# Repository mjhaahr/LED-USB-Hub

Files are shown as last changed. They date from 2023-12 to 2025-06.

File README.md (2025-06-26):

# 3-Port USB Hub with Integrated Microcontroller and RGB USB-A Ports

<!-- ![Assembled USB Hub](images/working-usb-hub.png) -->

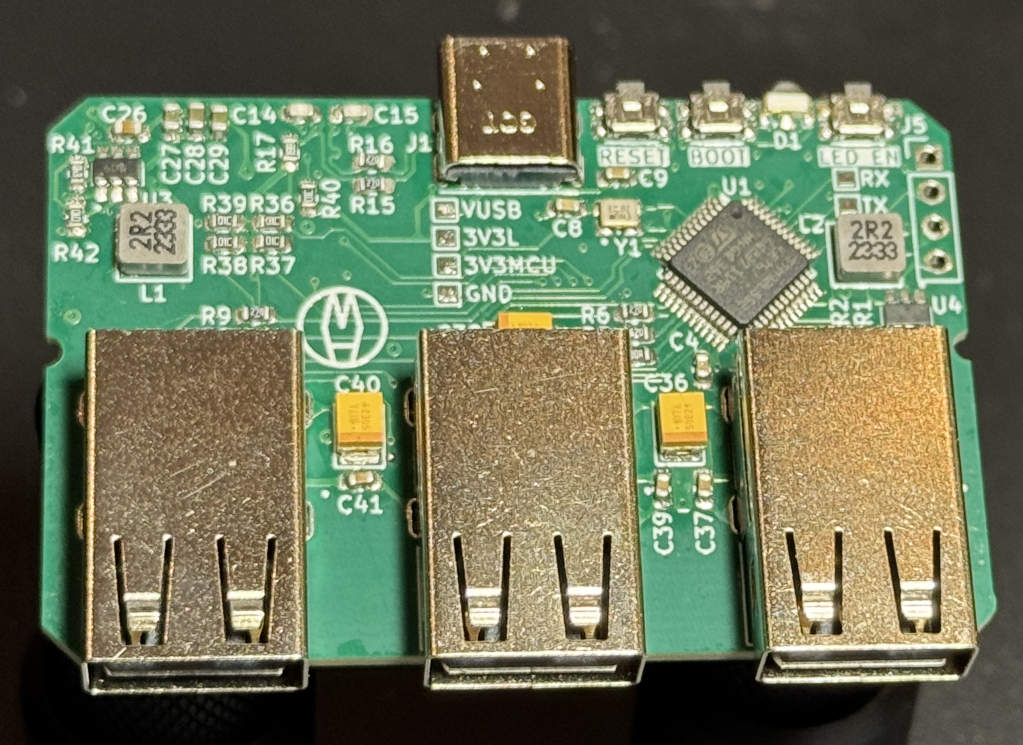
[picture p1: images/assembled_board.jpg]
Assembled PCB


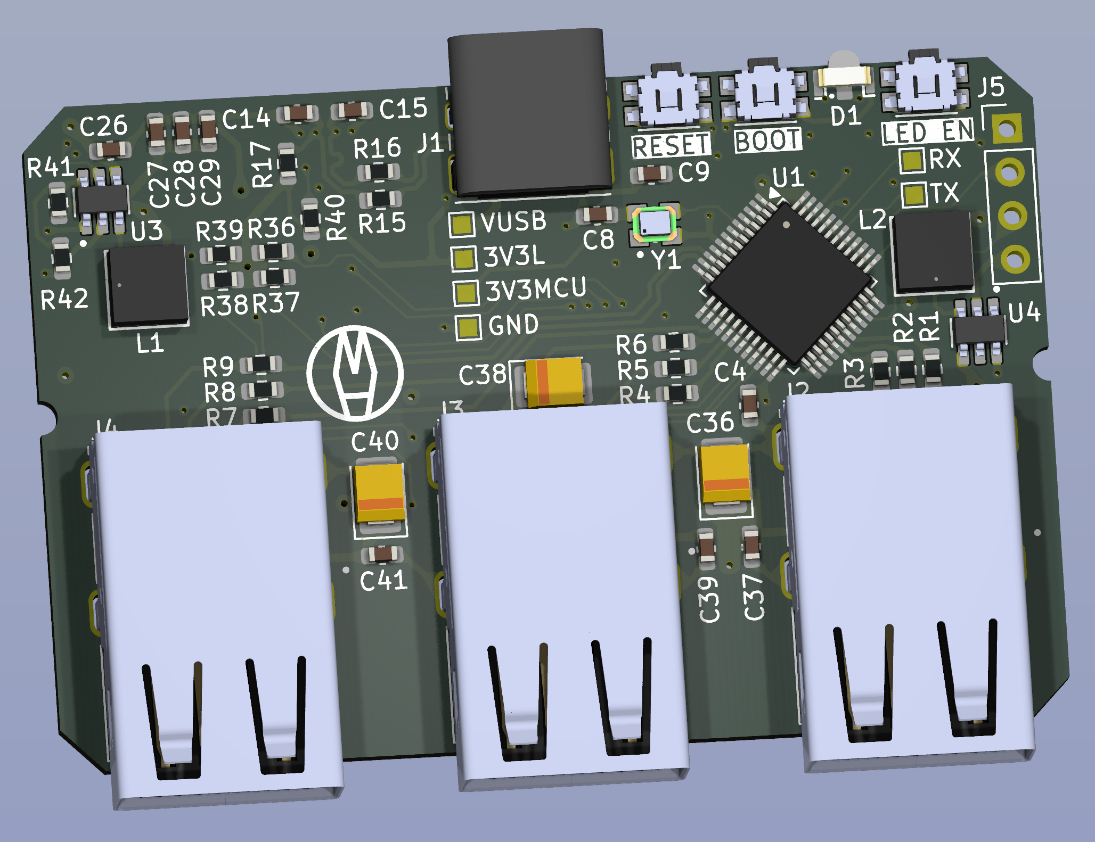
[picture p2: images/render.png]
Full Board Design Render

 
## Features
- USB C Port for Upstream
- 3 USB 2.0 Downstream Ports
    - USB A, Full Speed
    - Using RGB LED USB Ports (the reason behind this whole project)
- STM32L552 to Control the LEDs
    - Intended to be flashed using DFU, but SWD with Reset is available
- USB Hub Controller:
    - Using a TI 4 Port USB Controller
- Status LEDs for Power and USB Connection

## PCBWay
Version 3 of the RGB LED USB Hub was kindly supported by PCBWay, who graciously provided the PCBs for this project.

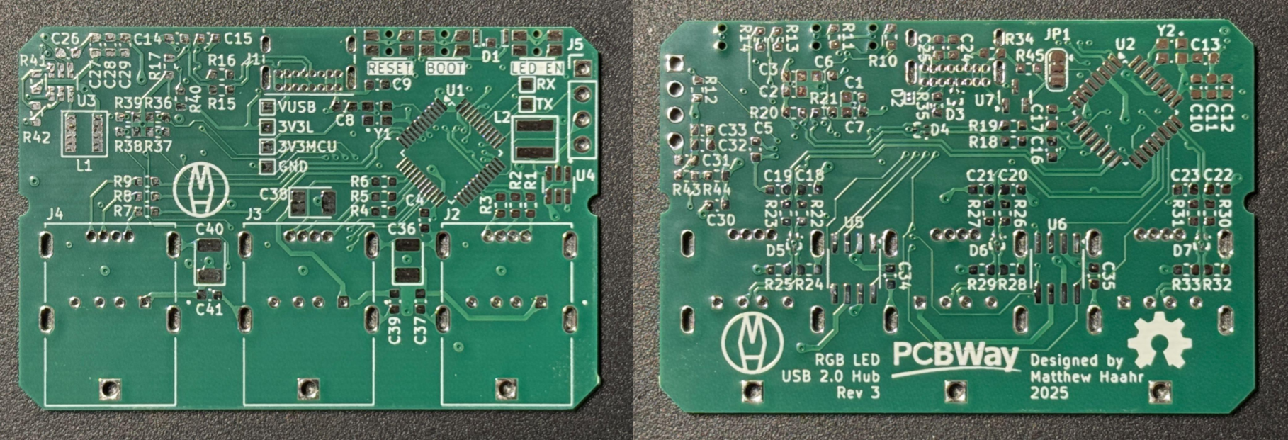
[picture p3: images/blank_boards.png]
Unassembled Boards


PCBWay offers very affordable and high-quality PCB manufacturing and assembly, as well as CNC machining and 3D printing, for hobbyists, low-volume prototyping, and even commercial use. They provide fast turnaround times, an easy-to-use service, and highly accurate and detailed boards all at a low cost. Their Standard PCBs satisfy most needs for reliable circuit boards: offering precise boards, layer counts up to 14, a wide variety of soldermask and silkscreen colors - even full color printing, and different materials like aluminum. But they also offer Advanced PCBs for even greater capabilities and performance or Flexible/Rigid-Flex PCBs when the designs need to bend. 

PCBWay Logo

## Table Of Contents
- [Features](#features)
- [PCBWay](#pcbway)
- [Bill Of Materials](#bill-of-materials)
- [Part Selection](#part-selection)
- [Case Design](#case-design)
- [Code](#code)
- [Extra Notes](#extra-notes)

Schematic

## Bill of Materials
<!--  [Digi-Key Cart with all components]() -->
<!--  TODO: Create new DigiKey Cart -->
<!--  
    - NAME - FUNC
        - Component: REF
        - Quantity: 
        - [Datasheet]()
        - [DigiKey]()
-->
- ICs
    - STMicroelectronics STM32L552CET6 - Microcontroller w/ USB and Multiple PWM Timers
        - Component: U1
        - Quantity: 1
        - [Datasheet](https://www.st.com/resource/en/datasheet/stm32l552cc.pdf)
        - [DigiKey](https://www.DigiKey.com/en/products/detail/stmicroelectronics/STM32L552CET6/11591114)
    - TI TUSB2046 - 4 Port USB 2.0 Hub/Controller
        - Component: U2
        - Quantity: 1
        - [Datasheet](https://www.ti.com/lit/ds/symlink/tusb2046i.pdf)
        - [DigiKey](https://www.DigiKey.com/en/products/detail/texas-instruments/TUSB2046IBVF/7400166)
    - TI TLV62569 - High Efficiency Buck Converter (3V3 Regulator)
        - Component: U3, U4
        - Quantity: 2
        - [Datasheet](https://www.ti.com/lit/ds/symlink/tlv62569.pdf)
        - [DigiKey](https://www.DigiKey.com/en/products/detail/texas-instruments/TLV62569PDDCR/8106072)
    - TI TPS2042BDR - USB Power Switch (500 mA)
        - Component: U5, U6
        - Quantity: 2
        - [Datasheet](https://www.ti.com/lit/ds/symlink/tps2042b.pdf)
        - [DigiKey](https://www.digikey.com/en/products/detail/texas-instruments/TPS2042BDR/656532)
    - Analog Devices/Maxim Integrated MAX809 - 3V Power Supervisor
        - Component: U7
        - Quantity: 1
        - [Datasheet](https://www.analog.com/media/en/technical-documentation/data-sheets/max803-max810z.pdf)
        - [DigiKey](https://www.DigiKey.com/en/products/detail/analog-devices-inc-maxim-integrated/MAX809TEUR-T/1173228)
- Diodes
    - Broadcom HSMF-C143 - Dual Color (Amber: Power/Green: USB) Status LED
        - Component: D1
        - Quantity: 1
        - [Datasheet](https://mm.digikey.com/Volume0/opasdata/d220001/medias/docus/2369/HSMF-C143.pdf)
        - [DigiKey](https://www.digikey.com/en/products/detail/HSMF-C143/5800153)    
    - TI ESD441- 1-Channel VUSB ESD Diode
        - Component: D2
        - Quantity: 1
        - [Datasheet](https://www.ti.com/lit/ds/symlink/esd441.pdf)
        - [DigiKey](https://www.DigiKey.com/en/products/detail/texas-instruments/ESD441DPLR/21298753)    
    - TI TPD2EUSB30 - 2-Channel USB ESD/TVS Diode
        - Component: D3, D4, D5, D6, D7
        - Quantity: 5
        - [Datasheet](https://www.ti.com/lit/ds/symlink/tpd2eusb30.pdf)
        - [DigiKey](https://www.DigiKey.com/en/products/detail/texas-instruments/TPD2EUSB30DRTR/2193486)
- Connectors
    - GCT USB4085-GF-A - USB 2.0 Type C Port
        - Component: J1
        - Quantity: 1
        - [Datasheet](https://gct.co/files/drawings/usb4085.pdf)
        - [DigiKey](http://DigiKey.com/en/products/detail/gct/USB4085-GF-A/9859662)
    - Tensility 54-00266 - RGB USB 2.0 Type A Port
        - Component: J2, J3, J4
        - Quantity: 3
        - [Datasheet](https://tensility.s3.us-west-2.amazonaws.com/uploads/pdffiles/54-00266.pdf)
        - [DigiKey](http://DigiKey.com/en/products/detail/tensility-international-corp/54-00266/17085369)
- Switches
    - Panasonic EVQ-P7L01P - Tactile Push Button
        - Component: SW1, SW2, SW3
        - Quantity: 3
        - [Datasheet](https://4donline.ihs.com/images/VipMasterIC/IC/PANA/PANAS45028/PANAS45028-1.pdf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)
        - [DigiKey](https://www.DigiKey.com/en/products/detail/panasonic-electronic-components/EVQ-P7L01P/4429453)
- Oscillators 
    - ECS ECS-2033-080-BN - STM32 8 MHz HSE
        - Component: Y1
        - Quantity: 1
        - [Datasheet](https://ecsxtal.com/store/pdf/ecs-2025-2033.pdf)
        - [DigiKey](https://www.digikey.com/en/products/detail/ecs-inc/ECS-2033-080-BN/1693364)
    - ECS ECS-2033-060-BN - USB Controller 6 MHz
        - Component: Y2
        - Quantity: 1
        - [Datasheet](https://ecsxtal.com/store/pdf/ecs-2025-2033.pdf)
        - [DigiKey](https://www.digikey.com/en/products/detail/ecs-inc/ECS-2033-060-BN/1693362)
- Capacitors
    - *All Components are 0603 MLCC Capacitors unless otherwise noted*
    - 100nF
        - Component: C1, C2, C3, C4, C5, C9, C11, C12, C34, C35, C37, C39, C41
        - Quantity: 13
        - [DigiKey](https://www.digikey.com/en/products/detail/yageo/CC0603KRX7R7BB104/302822)
    - 10µF
        - Component: C6, C25, C27, C28, C29, C31, C32, C33
        - Quantity: 8
        - [DigiKey](https://www.digikey.com/en/products/detail/yageo/CC0603MRX5R6BB106/5195224)
    - 1µF
        - Component: C7, C10, C24
        - Quantity: 3
        - [DigiKey](https://www.digikey.com/en/products/detail/yageo/CC0603KRX5R8BB105/2833610)
    - 10nF
        - Component: C8, C13
        - Quantity: 2
        - [DigiKey](https://www.digikey.com/en/products/detail/yageo/CC0603KRX7R8BB103/2103098)
    - 22pF
        - Component: C14, C15, C16, C17, C18, C19, C20, C21, C22, C23
        - Quantity: 10
        - [DigiKey](https://www.digikey.com/en/products/detail/yageo/CC0603JRNPO8BN220/5883592)
    - 4.7µF
        - Component: C26, C30
        - Quantity: 2
        - [DigiKey](https://www.digikey.com/en/products/detail/yageo/CC0603KRX5R7BB475/5195193)
    - 100µF - Tantalum
        - Component: C36, C38, C40
        - Quantity: 3
        - [DigiKey](https://www.digikey.com/en/products/detail/kyocera-avx/TAJB107K010RNJ/9748493)
- Resistors:
    - *All Components are 0603 Thick Film Resistors unless otherwise noted*
    - 200Ω
        - Component: R1, R4, R7
        - Quantity: 3
        - [DigiKey](https://www.digikey.com/en/products/detail/yageo/RC0603FR-13200RL/13694128)
    - 62Ω
        - Component: R2, R5, R8
        - Quantity: 3
        - [DigiKey](https://www.digikey.com/en/products/detail/yageo/RC0603FR-0762RL/727335)
    - 27Ω
        - Component: R3, R6, R9, R15, R16, R18, R19, R22, R23, R26, R27, R30, R31
        - Quantity: 13
        - [DigiKey](https://www.digikey.com/en/products/detail/yageo/RT0603BRD0727RL/1072412)
    - 10kΩ
        - Component: R10, R11, R12, R46, R47, R48, R40, R45
        - Quantity: 9
        - [DigiKey](https://www.digikey.com/en/products/detail/yageo/RC0603FR-0710KL/726880)
    - 1.74kΩ
        - Component: R13
        - Quantity: 1
        - [DigiKey](https://www.digikey.com/en/products/detail/yageo/RC0603FR-071K74L/726872)
    - 665Ω
        - Component: R14
        - Quantity: 1
        - [DigiKey](https://www.digikey.com/en/products/detail/yageo/RC0603FR-07665RL/727349)
    - 1.5kΩ
        - Component: R17
        - Quantity: 1
        - [DigiKey](https://www.digikey.com/en/products/detail/yageo/RC0603FR-071K5L/726864)
    - 15kΩ
        - Component: R20, R21, R24, R25, R28, R29, R32, R33
        - Quantity: 8
        - [DigiKey](https://www.digikey.com/en/products/detail/yageo/RC0603FR-0715KL/726953)
    - 5.1kΩ
        - Component: R34, R35
        - Quantity: 2
        - [DigiKey](https://www.digikey.com/en/products/detail/yageo/RC0603FR-075K1L/727268)
    - 453kΩ
        - Component: R41, R43
        - Quantity: 2
        - [DigiKey](https://www.digikey.com/en/products/detail/yageo/RC0603FR-07453KL/727247)
    - 100kΩ
        - Component: R42, R44
        - Quantity: 2
        - [DigiKey](https://www.digikey.com/en/products/detail/yageo/RC0603FR-07100KL/726889)
- Inductor
    - Bourns SRP4020FA-2R2M - 2.2µH Inductor
        - Component: L1, L2
        - Quantity: 2
        - [Datasheet](https://www.bourns.com/docs/Product-Datasheets/SRP4020FA.pdf)
        - [DigiKey](https://www.DigiKey.com/en/products/detail/bourns-inc/SRP4020FA-2R2M/9351010)
        
## Part Selection
- Power Supply selected using TI Webench Power Designer:
    - DC-DC: 5V In, 3.3V @ 1A (min) Out
    - High-Efficiency
    Power Supply Design
    - [Webench Page](https://webench.ti.com/appinfo/webench/scripts/SDP.cgi?ID=0260EB68D9ACEA79)
- LED Resistors:
    - Indicators:
        - Target Intensity of 2.5mcd
        - Amber:
            - Average 66mcd @ 20mA
            - Forward Voltage of 2V
            - Target Current: ~0.75mA
            - Resistance: 1.74kΩ
        - Green:
            - Average 25.5mcd @ 20mA
            - Forward Voltage of 2V
            - Target Current: ~1.96mA
            - Resistance: 665Ω
    - USB:
        - Target Intensity of 200mcd
        - Red:
            - Average 600mcd @ 20mA
            - Forward Voltage of 1.3V
            - Target Current: ~6.5mA
            - Resistance: 200Ω
        - Green:
            - Average 800mcd @ 20mA
            - Forward Voltage of 0.3V
            - Target Current: ~5mA
            - Resistance: 62Ω
        - Blue:
            - Average 350mcd @ 20mA
            - Forward Voltage of 0.3V
            - Target Current: ~11.5mA
            - Resistance: 27Ω
    
## Case Design
<!--  TODO: Case design needs to be updated  -->
<!--  ![Case](images/case.png)  -->
- 3D Printed Top and Bottom Covers

## Code
<!--  TODO: All code needs to be updated  -->
<!--
- The fork of CircuitPython for this device is located [here](https://github.com/mjhaahr/USB_Hub_CircuitPython)
    - If you would like just the firmware, that is [here](code/CircuitPython/firmware.uf2)
- `LED_EN` button cycles between the following states
    - All LEDs on
    - All LEDs on with dimmer Port LEDs
    - Just Port LEDs
    - Just Port LEDs but dimmer
    - Just Status LEDs
    - All Off
- To prevent the device from showing up as a removable storage device when connected, that's disabled on boot
    - To re-enable, hold the `LED_EN` button during boot, the `PWR_LED` should flash and the microcontroller will mount as removable storage (for things like firmware updates)
-->
- To view all the code, see it [here](code)

## Extra Notes
- Version 1:
    - V1 used an Adafruit KB2040 Dev Board instead of a standalone implementation
    - V1 used the SL2.1a USB Hub and was a poor attempt to get USB working
- Version 2:
    - Proper standalone RP2040 implementation
    - Switch to TUSB2046 4-Port USB Controller
    - Switch to 4 Layer Board with correct implementation of USB Hardware Guidelines
Assembled Version 2 USB Hub
- Version 3:
    - Switch to STM32 (STM32L552)
    - Shrink board
    - Switch to Oscillators from Crystals
    - 3V3 Regulators using a larger package
    - Fully Enclosed 3D Printed Case

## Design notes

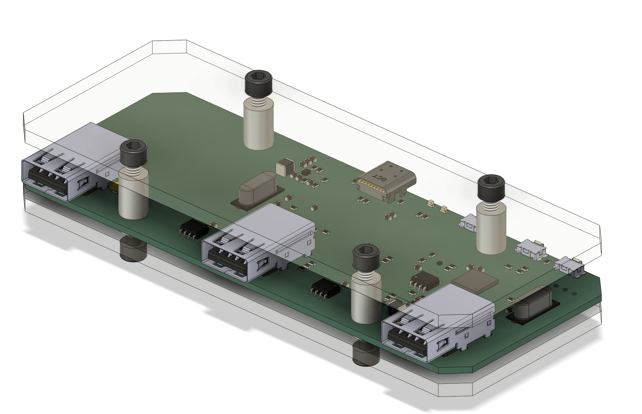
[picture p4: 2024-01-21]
images/case.png

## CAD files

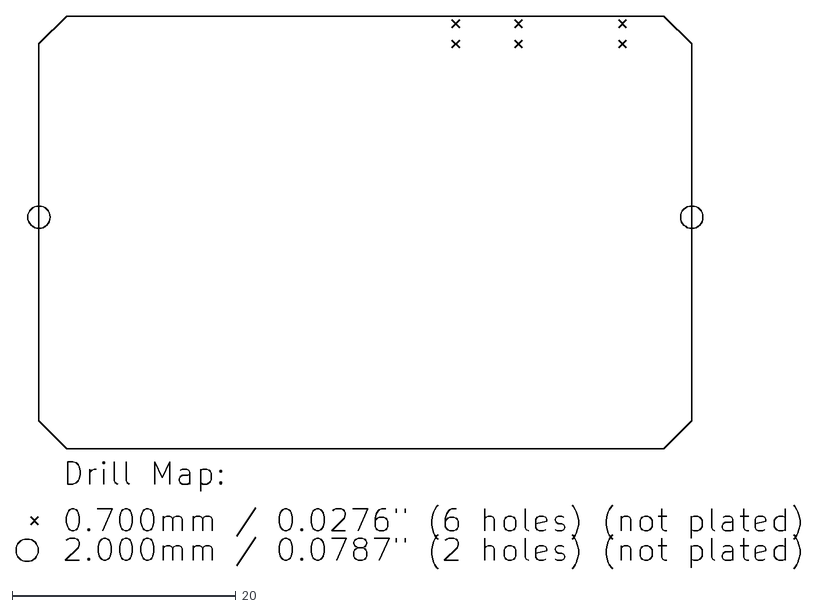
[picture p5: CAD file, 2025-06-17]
led-usb-hub/Gerbers/led-usb-hub-NPTH-drl_map.dxf
70.1 x 49.5

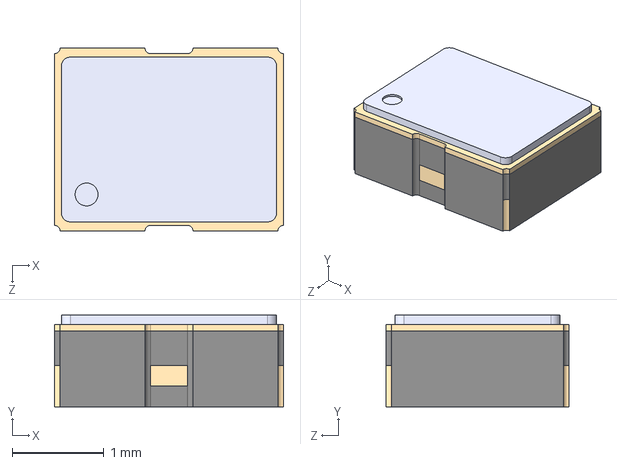
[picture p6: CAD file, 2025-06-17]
led-usb-hub/Parts/ECS_2033_060_BN/ECS-2033-060-BN.step
2.50 x 1.00 x 2.00 mm

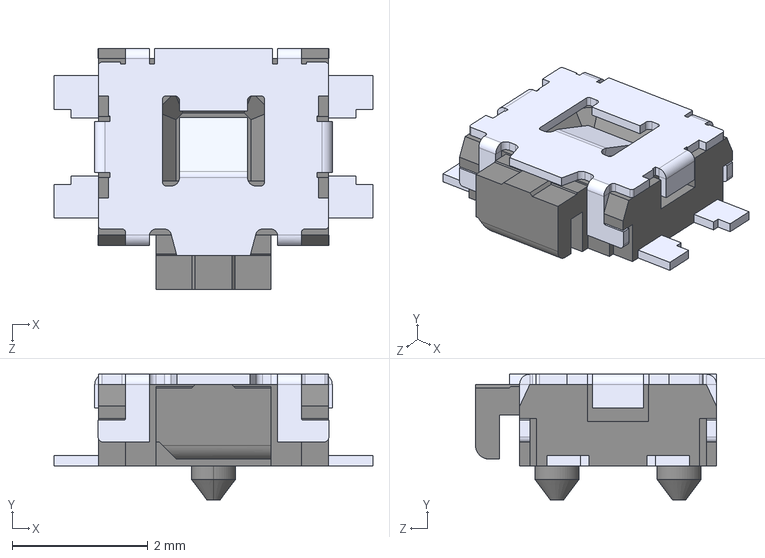
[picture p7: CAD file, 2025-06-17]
led-usb-hub/Parts/EVQ_P7L01P/EVQ-P7L01P.step
4.70 x 1.85 x 3.55 mm

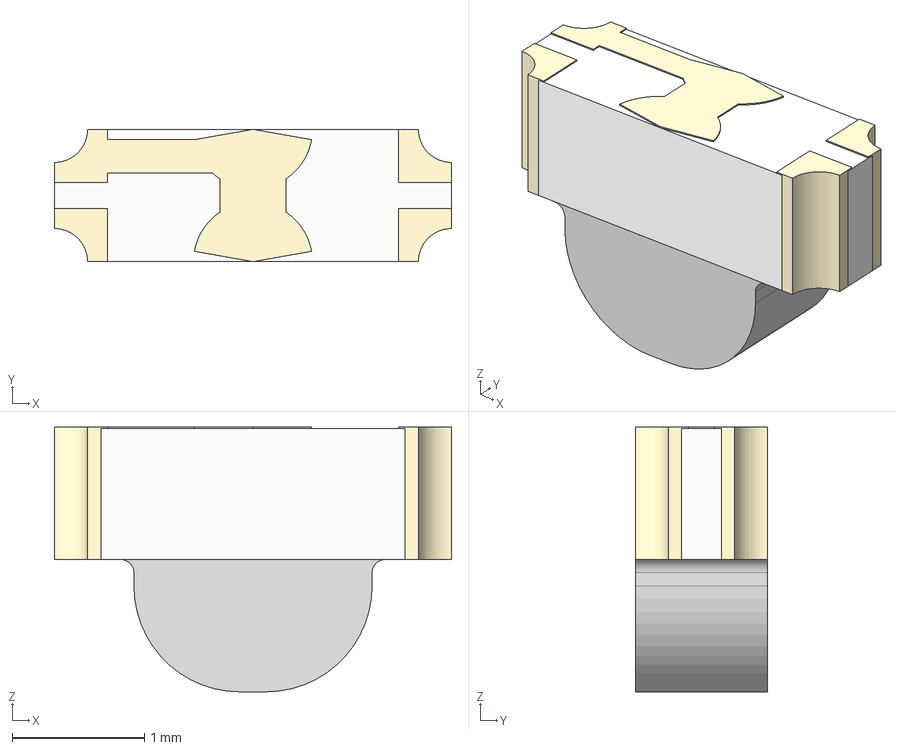
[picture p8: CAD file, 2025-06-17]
led-usb-hub/Parts/HSMF-C143/HSMF-C143.step
3.00 x 1.00 x 2.00 mm

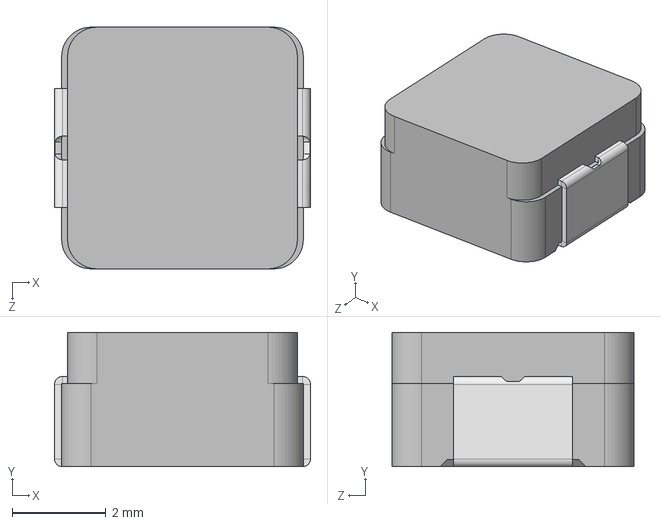
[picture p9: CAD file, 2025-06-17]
led-usb-hub/Parts/IHLP2020CZER2R2M11/IHLP2020CZ.step
5.45 x 2.86 x 5.15 mm

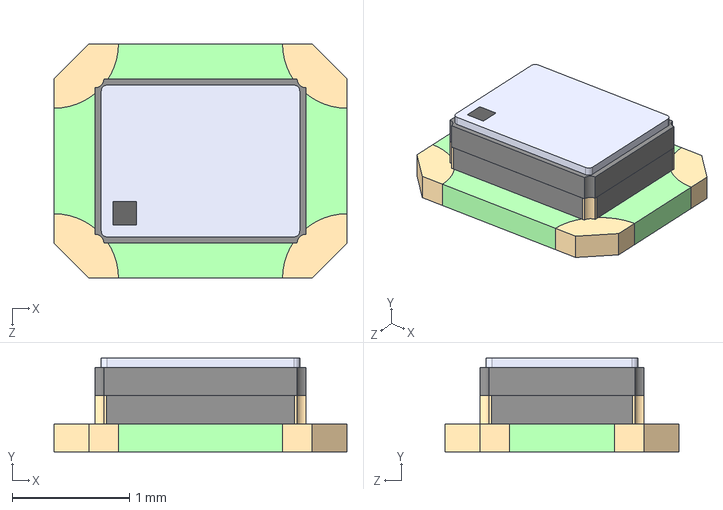
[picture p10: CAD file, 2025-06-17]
led-usb-hub/Parts/KC2520Z8_00000C1KX00/KC2520Z8.00000C1KX00.step
2.50 x 0.8 x 2.00 mm

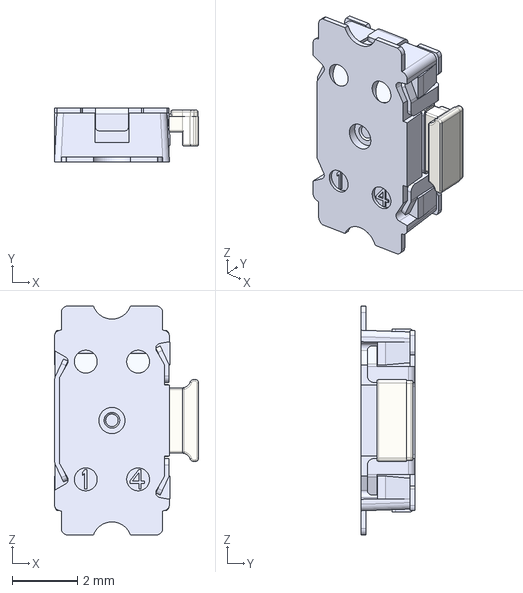
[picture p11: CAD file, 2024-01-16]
led-usb-hub/Parts/KSS221GLFS/KSS221GLFS.stp
4.41 x 1.65 x 7.00 mm

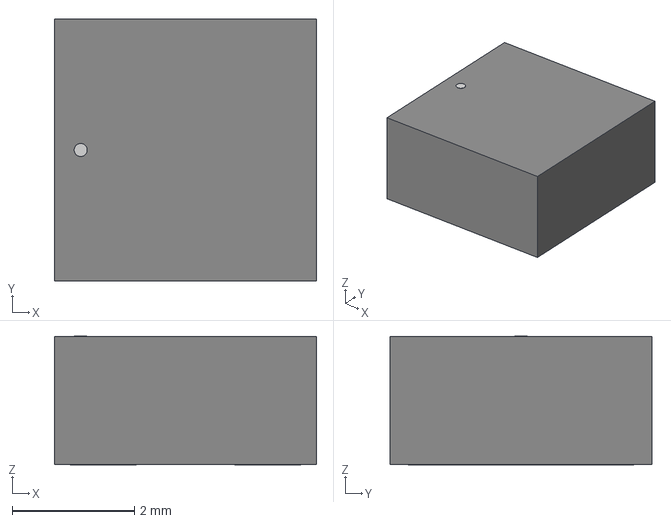
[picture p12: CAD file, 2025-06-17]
led-usb-hub/Parts/SRP4020FA_2R2M/IND_SRP4020FA-2R2M_BRN.step
4.29 x 4.29 x 2.11 mm

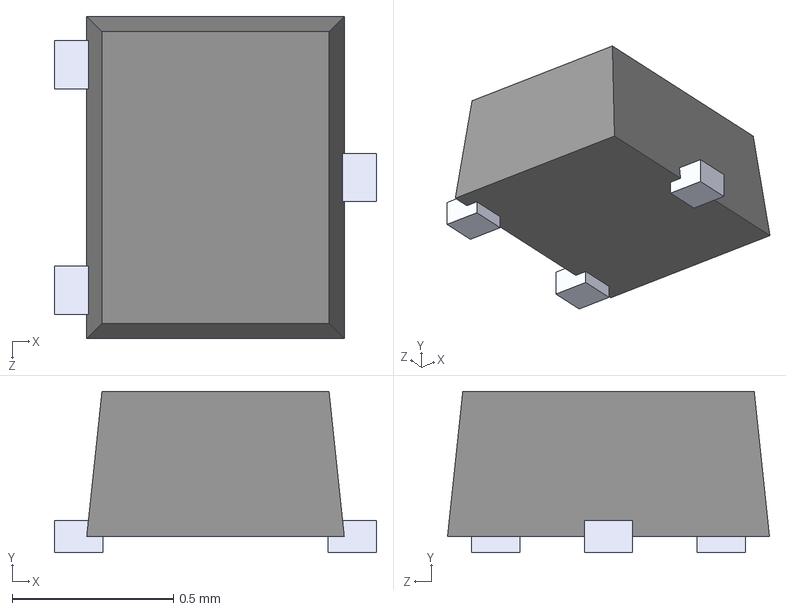
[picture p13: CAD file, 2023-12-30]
led-usb-hub/Parts/TPD2EUSB30DRTR/TPD2EUSB30DRTR.step
1.00 x 0.5 x 1.00 mm

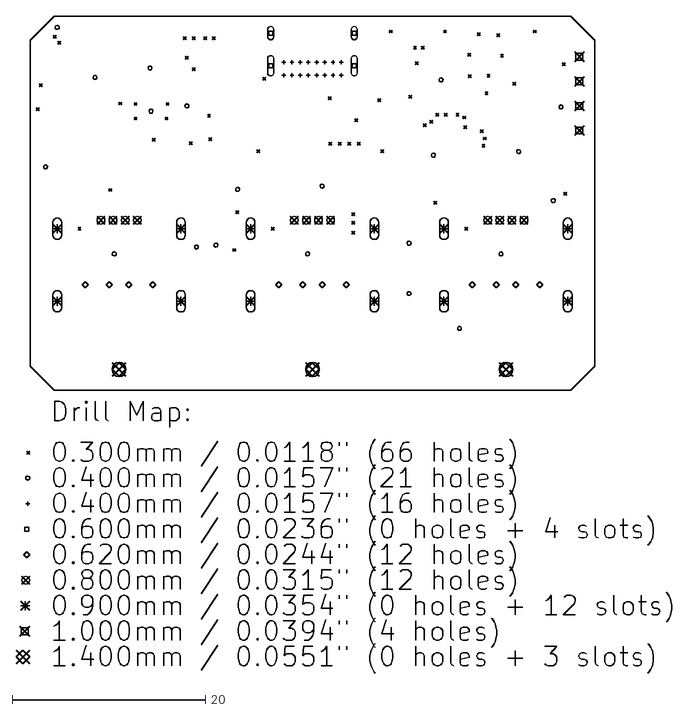
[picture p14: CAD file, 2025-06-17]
led-usb-hub/Gerbers/led-usb-hub-PTH-drl_map.dxf
67.8 x 67.9

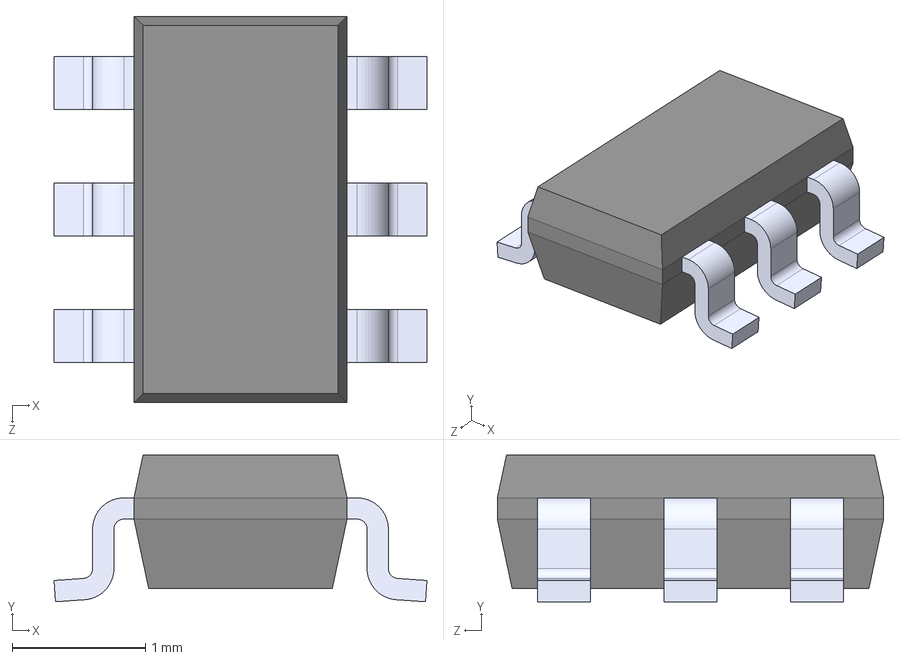
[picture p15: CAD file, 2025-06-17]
led-usb-hub/Parts/TLV62569PDDCR/TLV62569PDDCR.step
2.80 x 1.10 x 2.90 mm

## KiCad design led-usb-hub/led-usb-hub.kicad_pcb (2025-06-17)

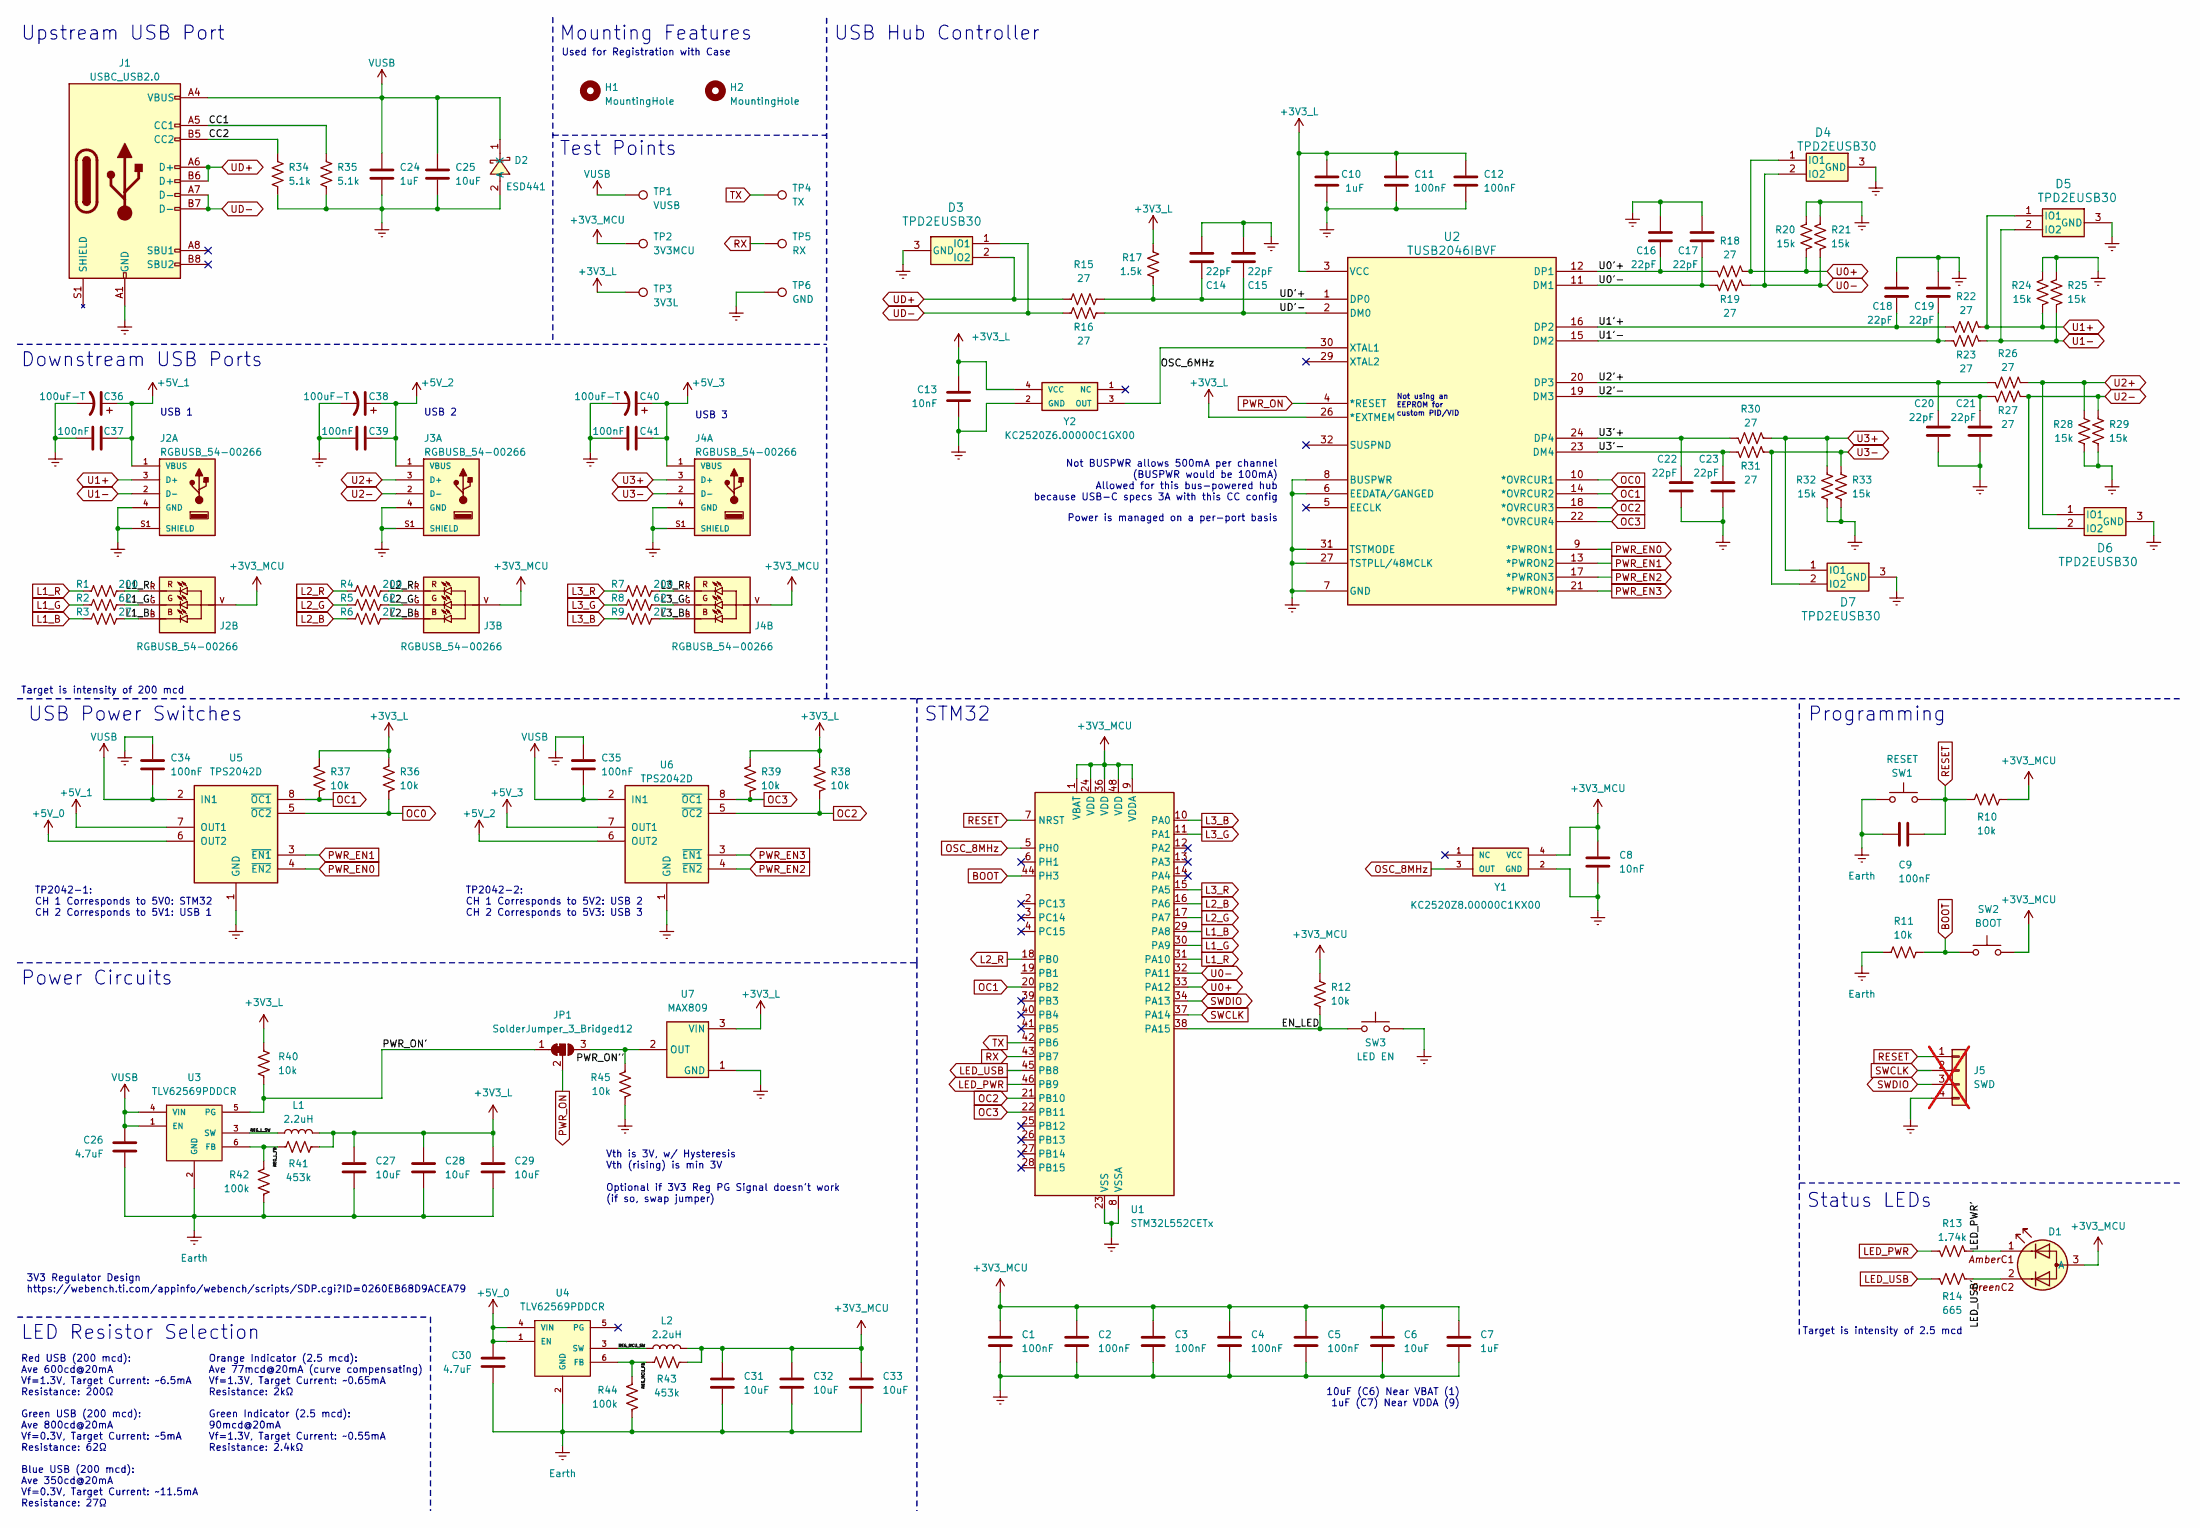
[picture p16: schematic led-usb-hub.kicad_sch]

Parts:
C1, C2, C3, C4, C5, C9: 100nF; C_0603_1608Metric; LCSC Part C7472949
C6: 10uF; C_0603_1608Metric; LCSC Part C7472949
C7: 1uF; C_0603_1608Metric; LCSC Part C7472949
C8, C13: 10nF; C_0603_1608Metric; LCSC Part C7472949
C10, C24: 1uF; C_0603_1608Metric
C11, C12, C34, C35, C37, C39, C41: 100nF; C_0603_1608Metric
C14, C15, C16, C17, C18, C19, C20, C21, C22, C23: 22pF; C_0603_1608Metric
C25, C27, C28, C29, C31, C32, C33: 10uF; C_0603_1608Metric
C26, C30: 4.7uF; C_0603_1608Metric
C36, C38, C40: 100uF-T; CP_EIA-3528-15_AVX-H
D1: HSMF-C143
D2: ESD441; X2SON-2_L0.6-W0.3-P0.35_ESD441DPLR; LCSC Part C22427765
D3, D4, D5, D6, D7: TPD2EUSB30; DRT0003A
H1, H2: MountingHole; MountingHole_2mm
J1: USBC_USB2.0; USB_C_Receptacle_GCT_USB4085
J2, J3, J4: RGBUSB_54-00266; PARTREV A; DigiKey_Part_Number 839-54-00266TR-ND
J5: SWD; PinHeader_1x04_P2.54mm_Vertical; not fitted
JP1: SolderJumper_3_Bridged12; SolderJumper-3_P1.3mm_Bridged12_RoundedPad1.0x1.5mm
L1, L2: 2.2uH; IND_SRP4020FA-2R2M_BRN
R1, R4, R7: 200; R_0603_1608Metric
R2, R5, R8: 62; R_0603_1608Metric
R3, R6, R9, R15, R16, R18, R19, R22, R23, R26, R27, R30, R31: 27; R_0603_1608Metric
R10, R11, R12, R36, R37, R38, R39, R40, R45: 10k; R_0603_1608Metric
R13: 1.74k; R_0603_1608Metric
R14: 665; R_0603_1608Metric
R17: 1.5k; R_0603_1608Metric
R20, R21, R24, R25, R28, R29, R32, R33: 15k; R_0603_1608Metric
R34, R35: 5.1k; R_0603_1608Metric
R41, R43: 453k; R_0603_1608Metric
R42, R44: 100k; R_0603_1608Metric
SW1: RESET; SW_EVQ-P7L01P
SW2: BOOT; SW_EVQ-P7L01P
SW3: LED EN; SW_EVQ-P7L01P
TP1: VUSB; TestPoint_Pad_1.0x1.0mm_Mod
TP2: 3V3MCU; TestPoint_Pad_1.0x1.0mm_Mod
TP3: 3V3L; TestPoint_Pad_1.0x1.0mm_Mod
TP4: TX; TestPoint_Pad_1.0x1.0mm_Mod
TP5: RX; TestPoint_Pad_1.0x1.0mm_Mod
TP6: GND; TestPoint_Pad_1.0x1.0mm_Mod
U1: STM32L552CETx; LQFP-48_7x7mm_P0.5mm
U2: TUSB2046IBVF; LQFP-32_7x7mm_P0.8mm
U3, U4: TLV62569PDDCR; SOT95P280X110-6N
U5, U6: TPS2042D; SOIC-8_3.9x4.9mm_P1.27mm
U7: MAX809; SOT-23
Y1: KC2520Z8.00000C1KX00; OSC_KC2520Z8.00000C1KX00; PARTREV October 16, 2023
Y2: KC2520Z6.00000C1GX00; OSC_KC2520Z6.00000C1GX00; PARTREV October 16, 2023; DigiKey_Part_Number 478-KC2520Z6.00000C1GX00TR-ND

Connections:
+3V3_L: C10.1, C11.1, C12.1, C13.1, C27.1, C28.1, C29.1, L1.2, R17.1, R36.2, R37.2, R38.2, R39.2, R40.2, R41.1, TP3.1, U2.3 (VCC), U2.25 (VCC), U2.26 (*EXTMEM), U7.3 (VIN), Y2.4 (VCC)
+3V3_MCU: C1.1, C2.1, C3.1, C4.1, C5.1, C6.1, C7.1, C8.1, C31.1, C32.1, C33.1, D1.3 (A), J2.V, J3.V, J4.V, L2.2, R10.2, R12.1, R43.1, SW2.1, TP2.1, U1.1 (VBAT), U1.9 (VDDA), U1.24 (VDD), U1.36 (VDD), U1.48 (VDD), Y1.4 (VCC)
+5V_0: C30.1, U4.1 (EN), U4.4 (VIN), U5.6 (OUT2)
+5V_1: C36.1, C37.1, J2.1 (VBUS), U5.7 (OUT1)
+5V_2: C38.1, C39.1, J3.1 (VBUS), U6.6 (OUT2)
+5V_3: C40.1, C41.1, J4.1 (VBUS), U6.7 (OUT1)
/CC1: J1.A5 (CC1), R35.2
/CC2: J1.B5 (CC2), R34.2
/EN_LED: R12.2, SW3.1, U1.38 (PA15)
/L1_B': J2.B, R3.2
/L1_G': J2.G, R2.2
/L1_R': J2.R, R1.2
/L2_B': J3.B, R6.2
/L2_G': J3.G, R5.2
/L2_R': J3.R, R4.2
/L3_B': J4.B, R9.2
/L3_G': J4.G, R8.2
/L3_R': J4.R, R7.2
/LED_PWR': D1.1, R13.2
/LED_USB': D1.2, R14.2
/OSC_6MHz: U2.30 (XTAL1), Y2.3 (OUT)
/PWR_ON': JP1.1 (A), R40.1, U3.5 (PG)
/PWR_ON'': JP1.3 (B), R45.2, U7.2 (OUT)
/REG_L_FB: R41.2, R42.2, U3.6 (FB)
/REG_L_SW: L1.1, U3.3 (SW)
/REG_MCU_FB: R43.2, R44.2, U4.6 (FB)
/REG_MCU_SW: L2.1, U4.3 (SW)
/U0'+: C16.1, R18.1, U2.12 (DP1)
/U0'-: C17.1, R19.1, U2.11 (DM1)
/U1'+: C18.1, R22.1, U2.16 (DP2)
/U1'-: C19.1, R23.1, U2.15 (DM2)
/U2'+: C20.1, R26.1, U2.20 (DP3)
/U2'-: C21.1, R27.1, U2.19 (DM3)
/U3'+: C22.1, R30.1, U2.24 (DP4)
/U3'-: C23.1, R31.1, U2.23 (DM4)
/UD'+: C14.1, R15.1, R17.2, U2.1 (DP0)
/UD'-: C15.1, R16.1, U2.2 (DM0)
BOOT: R11.1, SW2.2, U1.44 (PH3)
Earth: C1.2, C2.2, C3.2, C4.2, C5.2, C6.2, C7.2, C8.2, C9.2, C10.2, C11.2, C12.2, C13.2, C14.2, C15.2, C16.2, C17.2, C18.2, C19.2, C20.2, C21.2, C22.2, C23.2, C24.2, C25.2, C26.2, C27.2, C28.2, C29.2, C30.2, C31.2, C32.2, C33.2, C34.1, C35.1, C36.2, C37.2, C38.2, C39.2, C40.2, C41.2, D2.2 (A), D3.3 (GND), D4.3 (GND), D5.3 (GND), D6.3 (GND), D7.3 (GND), J1.A1 (GND), J1.A12 (GND), J1.B1 (GND), J1.B12 (GND), J2.4 (GND), J2.S1 (SHIELD), J2.S2 (SHIELD), J2.S3 (SHIELD), J2.S4 (SHIELD), J2.S5 (SHIELD), J3.4 (GND), J3.S1 (SHIELD), J3.S2 (SHIELD), J3.S3 (SHIELD), J3.S4 (SHIELD), J3.S5 (SHIELD), J4.4 (GND), J4.S1 (SHIELD), J4.S2 (SHIELD), J4.S3 (SHIELD), J4.S4 (SHIELD), J4.S5 (SHIELD), J5.4, R11.2, R20.2, R21.2, R24.2, R25.2, R28.2, R29.2, R32.2, R33.2, R34.1, R35.1, R42.1, R44.1, R45.1, SW1.2, SW3.2, TP6.1, U1.8 (VSSA), U1.23 (VSS), U1.35 (VSS), U1.47 (VSS), U2.6 (EEDATA/GANGED), U2.7 (GND), U2.8 (BUSPWR), U2.27 (TSTPLL/48MCLK), U2.28 (GND), U2.31 (TSTMODE), U3.2 (GND), U4.2 (GND), U5.1 (GND), U6.1 (GND), U7.1 (GND), Y1.2 (GND), Y2.2 (GND)
L1_B: R3.1, U1.29 (PA8)
L1_G: R2.1, U1.30 (PA9)
L1_R: R1.1, U1.31 (PA10)
L2_B: R6.1, U1.16 (PA6)
L2_G: R5.1, U1.17 (PA7)
L2_R: R4.1, U1.18 (PB0)
L3_B: R9.1, U1.10 (PA0)
L3_G: R8.1, U1.11 (PA1)
L3_R: R7.1, U1.15 (PA5)
LED_PWR: R13.1, U1.46 (PB9)
LED_USB: R14.1, U1.45 (PB8)
OC0: R36.1, U2.10 (*OVRCUR1), U5.5 (~OC2)
OC1: R37.1, U1.20 (PB2), U2.14 (*OVRCUR2), U5.8 (~OC1)
OC2: R38.1, U1.21 (PB10), U2.18 (*OVRCUR3), U6.5 (~OC2)
OC3: R39.1, U1.22 (PB11), U2.22 (*OVRCUR4), U6.8 (~OC1)
OSC_8MHz: U1.5 (PH0), Y1.3 (OUT)
PWR_EN0: U2.9 (*PWRON1), U5.4 (~EN2)
PWR_EN1: U2.13 (*PWRON2), U5.3 (~EN1)
PWR_EN2: U2.17 (*PWRON3), U6.4 (~EN2)
PWR_EN3: U2.21 (*PWRON4), U6.3 (~EN1)
PWR_ON: JP1.2 (C), U2.4 (*RESET)
RESET: C9.1, J5.1, R10.1, SW1.1, U1.7 (NRST)
RX: TP5.1, U1.43 (PB7)
SWCLK: J5.2, U1.37 (PA14)
SWDIO: J5.3, U1.34 (PA13)
TX: TP4.1, U1.42 (PB6)
U0+: D4.1 (IO1), R18.2, R20.1, U1.33 (PA12)
U0-: D4.2 (IO2), R19.2, R21.1, U1.32 (PA11)
U1+: D5.1 (IO1), J2.3 (D+), R22.2, R24.1
U1-: D5.2 (IO2), J2.2 (D-), R23.2, R25.1
U2+: D6.1 (IO1), J3.3 (D+), R26.2, R28.1
U2-: D6.2 (IO2), J3.2 (D-), R27.2, R29.1
U3+: D7.1 (IO1), J4.3 (D+), R30.2, R32.1
U3-: D7.2 (IO2), J4.2 (D-), R31.2, R33.1
UD+: D3.2 (IO2), J1.A6 (D+), J1.B6 (D+), R15.2
UD-: D3.1 (IO1), J1.A7 (D-), J1.B7 (D-), R16.2
VUSB: C24.1, C25.1, C26.1, C34.2, C35.2, D2.1 (K), J1.A4 (VBUS), J1.A9 (VBUS), J1.B4 (VBUS), J1.B9 (VBUS), TP1.1, U3.1 (EN), U3.4 (VIN), U5.2 (IN1), U6.2 (IN1)

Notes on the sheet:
USB 2
Not BUSPWR allows 500mA per channel (BUSPWR would be 100mA) Allowed for this bus-powered hub because USB-C specs 3A with this CC config
USB Hub Controller
LED Resistor Selection
Upstream USB Port
Target is intensity of 200 mcd
STM32
Status LEDs
Blue USB (200 mcd): Ave 350cd@20mA Vf=0.3V, Target Current: ~11.5mA Resistance: 27Ω
Orange Indicator (2.5 mcd): Ave 77mcd@20mA (curve compensating) Vf=1.3V, Target Current: ~0.65mA Resistance: 2kΩ
USB Power Switches
TP2042-2: CH 1 Corresponds to 5V2: USB 2 CH 2 Corresponds to 5V3: USB 3
Downstream USB Ports
Not using an EEPROM for custom PID/VID
Vth is 3V, w/ Hysteresis Vth (rising) is min 3V Optional if 3V3 Reg PG Signal doesn't work (if so, swap jumper)
TP2042-1: CH 1 Corresponds to 5V0: STM32 CH 2 Corresponds to 5V1: USB 1
3V3 Regulator Design https://webench.ti.com/appinfo/webench/scripts/SDP.cgi?ID=0260EB68D9ACEA79
Green USB (200 mcd): Ave 800cd@20mA Vf=0.3V, Target Current: ~5mA Resistance: 62Ω
USB 3
Programming
USB 1
10uF (C6) Near VBAT (1) 1uF (C7) Near VDDA (9)
Test Points
Mounting Features
Target is intensity of 2.5 mcd
Power Circuits
Green Indicator (2.5 mcd): 90mcd@20mA Vf=1.3V, Target Current: ~0.55mA Resistance: 2.4kΩ
Power is managed on a per-port basis
Red USB (200 mcd): Ave 600cd@20mA Vf=1.3V, Target Current: ~6.5mA Resistance: 200Ω
Used for Registration with Case

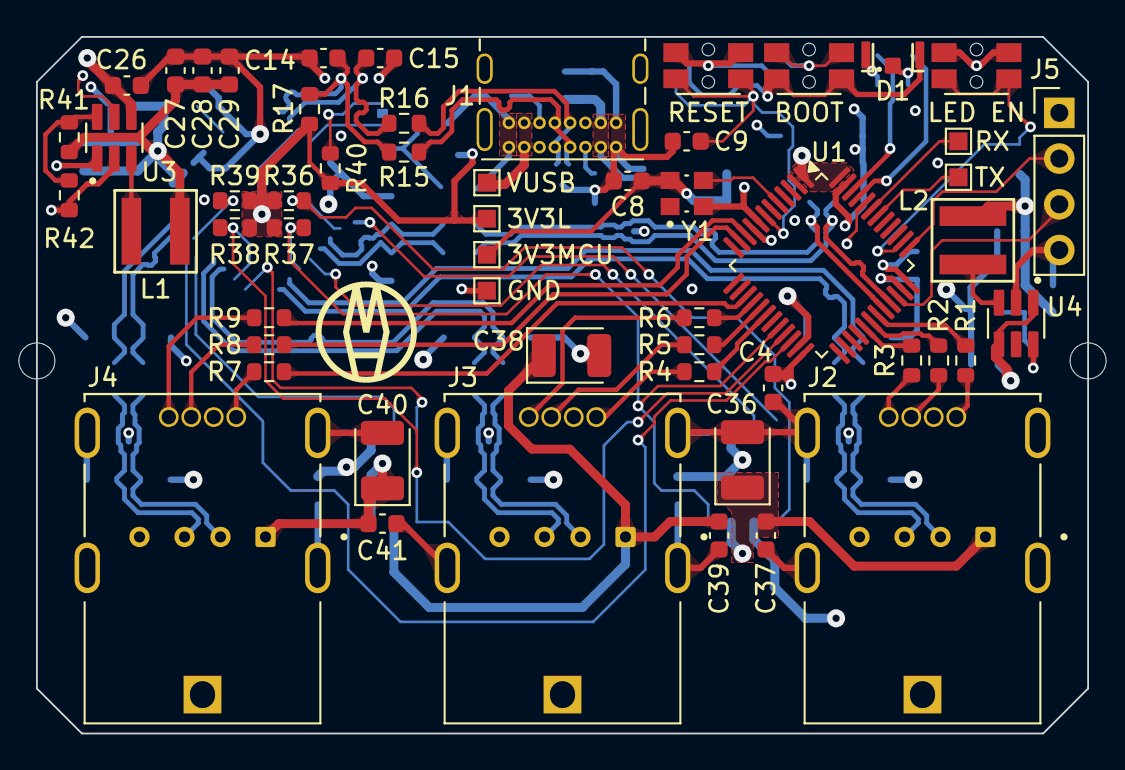
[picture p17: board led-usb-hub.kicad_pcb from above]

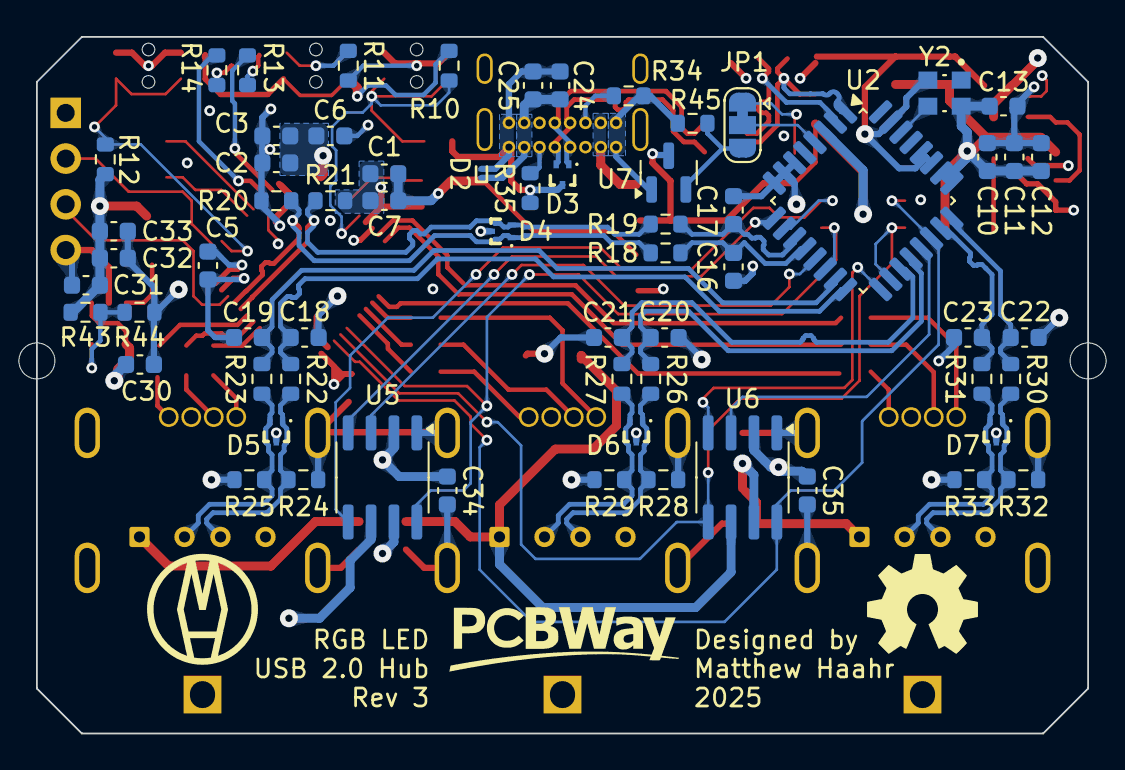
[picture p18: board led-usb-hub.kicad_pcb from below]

Board: 4 copper layers, 58.4 x 38.7 mm, 124 parts (66 on the bottom side), 76 nets.

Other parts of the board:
G1, G2, G3: LOGO

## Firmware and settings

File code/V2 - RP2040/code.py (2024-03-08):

import board
import digitalio
import time
import supervisor
import adafruit_rgbled
import keypad

# Init LEDs
L1 = adafruit_rgbled.RGBLED(board.L1R, board.L1G, board.L1B, True)
L2 = adafruit_rgbled.RGBLED(board.L2R, board.L2G, board.L2B, True)
L3 = adafruit_rgbled.RGBLED(board.L3R, board.L3G, board.L3B, True)

pwrLED = digitalio.DigitalInOut(board.PWR_LED)
pwrLED.direction = digitalio.Direction.OUTPUT
pwrLED.value = True

usbLED = digitalio.DigitalInOut(board.USB_LED)
usbLED.direction = digitalio.Direction.OUTPUT

leds = [L1, L2, L3]

# Add Keypad object for the button (enables debouncing)
button = keypad.Keys((board.LED_EN,), value_when_pressed=False, pull=True)
button.events.get()
# Get a first dangling event (from possibly holding down the button

def colorWheel(pos):
    # Input a value 0 to 255 to get a color value.
    # The colours are a transition r - g - b - back to r.
    if pos < 0 or pos > 255:
        return (0, 0, 0)
    if pos < 85:
        return (255 - pos * 3, pos * 3, 0)
    if pos < 170:
        pos -= 85
        return (0, 255 - pos * 3, pos * 3)
    pos -= 170
    return (pos * 3, 0, 255 - pos * 3)


pos = 0

print("Starting LEDs")

state = 0
# 0: All on, 1: All on dim, 2: Just Ports, 3: Just Ports dim
# 4: Status LEDs only, 5: All Off

while True:
    buttonEvent = button.events.get()
    if buttonEvent:
        if buttonEvent.pressed:
            state = (state + 1) % 6
            print(f"State: {state}")

    colors = []
    for i in range(len(leds)):
        wheelPos = (pos + (i * 25)) % 256
        newColor = colorWheel(wheelPos)
        colors.append(newColor)

    pos = (pos + 1) % 256

    usbStatus = supervisor.runtime.usb_connected

    if state == 0:
        # All on
        for led, color in zip(leds, colors):
            led.color = color

        usbLED.value = usbStatus
        pwrLED.value = True

    elif state == 1:
        # All on, dim
        for led, color in zip(leds, colors):
            led.color = tuple(i // 3 for i in color)

        usbLED.value = usbStatus
        pwrLED.value = True

    elif state == 2:
        # Ports only
        for led, color in zip(leds, colors):
            led.color = color

        usbLED.value = False
        pwrLED.value = False

    elif state == 3:
        # Ports only, dim
        for led, color in zip(leds, colors):
            led.color = tuple(i // 3 for i in color)

        usbLED.value = False
        pwrLED.value = False

    elif state == 4:
        # Status only
        for led in leds:
            led.color = (0, 0, 0)

        usbLED.value = usbStatus
        pwrLED.value = True

    else:
        # All off
        for led in leds:
            led.color = (0, 0, 0)

        usbLED.value = False
        pwrLED.value = False

    time.sleep(0.01)

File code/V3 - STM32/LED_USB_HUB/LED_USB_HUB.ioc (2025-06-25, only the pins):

Mcu.UserName=STM32L552CETx
PA1.GPIO_Label=USB3_BLUE
PA1.Signal=S_TIM2_CH2
PA10.GPIO_Label=USB1_RED
PA10.Signal=S_TIM1_CH3
PA11.Signal=USB_DM
PA12.Signal=USB_DP
PA2.GPIO_Label=USB3_GREEN
PA2.Signal=S_TIM2_CH3
PA5.GPIO_Label=USB3_RED
PA5.Signal=S_TIM2_CH1
PA6.GPIO_Label=USB2_BLUE
PA6.Signal=S_TIM3_CH1
PA7.GPIO_Label=USB2_GREEN
PA7.Signal=S_TIM3_CH2
PA8.GPIO_Label=USB1_BLUE
PA8.Signal=S_TIM1_CH1
PA9.GPIO_Label=USB1_GREEN
PA9.Signal=S_TIM1_CH2
PB0.GPIO_Label=USB2_RED
PB0.Signal=S_TIM3_CH3
PB10.GPIO_Label=USB2_OC
PB10.Signal=GPIO_Input
PB11.GPIO_Label=USB3_OC
PB11.Signal=GPIO_Input
PB2.GPIO_Label=USB1_OC
PB2.Signal=GPIO_Input
PB6.Signal=USART1_TX
PB7.Signal=USART1_RX
PB8.GPIO_Label=LED_USB
PB8.Signal=GPIO_Output
PB9.GPIO_Label=LED_PWR
PB9.Signal=GPIO_Output
PH3-BOOT0.GPIO_Label=BOOT_BUTTON
PH3-BOOT0.Signal=GPIO_Input

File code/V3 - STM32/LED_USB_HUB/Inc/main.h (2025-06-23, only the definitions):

#define HSI_IN_Pin GPIO_PIN_0
#define HSI_IN_GPIO_Port GPIOH
#define HSI_OUT_Pin GPIO_PIN_1
#define HSI_OUT_GPIO_Port GPIOH
#define USB3_BLUE_Pin GPIO_PIN_1
#define USB3_BLUE_GPIO_Port GPIOA
#define USB3_GREEN_Pin GPIO_PIN_2
#define USB3_GREEN_GPIO_Port GPIOA
#define USB3_RED_Pin GPIO_PIN_5
#define USB3_RED_GPIO_Port GPIOA
#define USB2_BLUE_Pin GPIO_PIN_6
#define USB2_BLUE_GPIO_Port GPIOA
#define USB2_GREEN_Pin GPIO_PIN_7
#define USB2_GREEN_GPIO_Port GPIOA
#define USB2_RED_Pin GPIO_PIN_0
#define USB2_RED_GPIO_Port GPIOB
#define USB1_OC_Pin GPIO_PIN_2
#define USB1_OC_GPIO_Port GPIOB
#define USB2_OC_Pin GPIO_PIN_10
#define USB2_OC_GPIO_Port GPIOB
#define USB3_OC_Pin GPIO_PIN_11
#define USB3_OC_GPIO_Port GPIOB
#define USB1_BLUE_Pin GPIO_PIN_8
#define USB1_BLUE_GPIO_Port GPIOA
#define USB1_GREEN_Pin GPIO_PIN_9
#define USB1_GREEN_GPIO_Port GPIOA
#define USB1_RED_Pin GPIO_PIN_10
#define USB1_RED_GPIO_Port GPIOA
#define SWDIO_Pin GPIO_PIN_13
#define SWDIO_GPIO_Port GPIOA
#define SWCLK_Pin GPIO_PIN_14
#define SWCLK_GPIO_Port GPIOA
#define LED_EN_BUTTON_Pin GPIO_PIN_15
#define LED_EN_BUTTON_GPIO_Port GPIOA
#define BOOT_BUTTON_Pin GPIO_PIN_3
#define BOOT_BUTTON_GPIO_Port GPIOH
#define LED_USB_Pin GPIO_PIN_8
#define LED_USB_GPIO_Port GPIOB
#define LED_PWR_Pin GPIO_PIN_9
#define LED_PWR_GPIO_Port GPIOB

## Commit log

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2023-07-12 Start Schematic USB Controller and USB-C Upstream Added
    [led-usb-hub.kicad_sch]
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2023-08-03 Cont Routing Need: Osc, Switch, USB port (check part inventory for all Design switch action before commiting design
    [led-usb-hub.kicad_pcb]
2023-08-04 Cont routing Need footprints for SW and Osc Need mounting holes in corners
    [led-usb-hub.kicad_pcb]
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2023-12-27 Update Schematic: Start Switch to new TI parts Add USB Power Switches Clean Up
    [led-usb-hub.kicad_sch]
2023-12-27 Add USB Parts TODO: Crystals (6 MHz for USB cont 12 MHz for Pi) TODO: RP2040 Stuff (caps, buttons for boot and reset, flash) TODO: Wire up LEDs (and add PWR and USB data present LEDs) Maybe TODO: add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
    [led-usb-hub.kicad_sch]
2023-12-27 Remove TODO: BUSPWR is fine b/c USB-C is a 15W spec
    [led-usb-hub.kicad_sch]
2023-12-27 Add Caps for RP2040 and correct values (caps, series and pullup resistors TODO: Crystals TODO: Bootsel and Reset Buttons TODO: Flash TODO: LEDs for PWR and USB Link Maybe TODO: internal connectors
    [led-usb-hub.kicad_sch]
2023-12-27 Swap ESD Diode to larger package Add missing resistors to Power Circuits Assign footprints to most components TODO: Footprints for inductors and tantalum caps (pick parts) TODO: 3D Models for USB Por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
    [led-usb-hub.kicad_pcb, led-usb-hub.kicad_sch]
2023-12-27 Add Reset Power On Chip Holds Reset Low (in Reset state) for 200 us while clock starts to allow logic to be enabled on the USB controller
    [led-usb-hub.kicad_pcb, led-usb-hub.kicad_sch]
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2023-12-28 Add Crystals and fix USB models TODOS: Status LEDs TODO: Buttons (RST,BOOTSEL,LEDs) TODO: Flash Chip TODO: Spec Inductors and Tantalum Caps (see TUSB and TPS docs)
    [led-usb-hub.kicad_pcb, led-usb-hub.kicad_sch]
2023-12-28 Add Boot Flash, SWD Header, and Reset and BOOTSEL Buttons TODO: Spec Inductors and Tantalum Caps (see TUSB and TPS docs) TODO: Status LEDs TODO: LED Enable Button TODO: spec buttons and model them
    [led-usb-hub.kicad_pcb, led-usb-hub.kicad_sch]
2023-12-28 Add LEDs to schematic For LED function: make button cycle between ports and status, just ports, all off TODO: Pick LEDs and find resistor values for that (orange and green) TODO: spec inductors and t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
    [led-usb-hub.kicad_sch]
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2023-12-29 Spec LEDs TODO: Footprints and models for KSS221 Switches TODO: spec inductors and tantalum caps Then layout (but also find all the rest of the passives necessary, some sizes may change)
    [led-usb-hub.kicad_pcb, led-usb-hub.kicad_sch]
2023-12-29 Update README.md
    Added LEDs
    Still missing Caps, Resistors, and Inductors
2023-12-29 Add Footprints and models for switches TODO: Spec all passives to finalize footprints (if staying at 0603) TODO: Find Inductor and C-T footprints Then it's layout
    [KSS221GLFS.stp, led-usb-hub.kicad_pcb, led-usb-hub.kicad_sch]
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2023-12-29 Remove model of SWD pins, show as unpopulated
    [led-usb-hub.kicad_pcb]
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2023-12-30 All Components have first pass footprints, need to go through all passives to verify
    [led-usb-hub.kicad_pcb, led-usb-hub.kicad_sch]
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2023-12-30 Add 0.1uF decoupling caps for USB Power Switches, rec by TI
    [led-usb-hub.kicad_sch]
2023-12-30 Start layout ideas, mostly just figure out where components will go
    [led-usb-hub.kicad_pcb]
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2023-12-30 Switch TVS diode for one that's easier to route Figure out how to route diff traces
    [TPD2EUSB30DRTR.step, led-usb-hub.kicad_pcb, led-usb-hub.kicad_sch]
2023-12-31 Fix decoupling cap count and start component arrangement
    [led-usb-hub.kicad_pcb, led-usb-hub.kicad_sch]
2023-12-31 Flip USB Hub Controller for better routing, continue placing components swap sizes of 0603 to not hand soldering
    [led-usb-hub.kicad_pcb, led-usb-hub.kicad_sch]
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2024-01-01 Finalize some component placement and route all differential traces (may end up condensing later)
    [led-usb-hub.kicad_pcb]
2024-01-01 Continue rotuing and component placing: Still TODO: RP2040 (basically everything, but USB) QSPI Flash 12 MHz osc LED Traces OC and PWR lines for USB PWR and the pullups Buttons Mounting Holes
    [led-usb-hub.kicad_pcb, led-usb-hub.kicad_sch]
2024-01-01 Cont rotuing, add mounting holes, do RP2040 Still todo: Power Control PWR and OC lines and associated pullups USB Port RGB lines, and the 3v3 line for that as well (make a trunk line under) DRC passi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
    [led-usb-hub.kicad_pcb, led-usb-hub.kicad_sch]
2024-01-02 Finish routing, need some verification and checking to ensure that it's good before I order
    [led-usb-hub.kicad_pcb]
2024-01-02 Increase minimum via size Update and clean up
    [led-usb-hub.kicad_pcb]
2024-01-03 Fix angles on board edges
    [led-usb-hub.kicad_pcb]
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2024-01-12 Add descriptive text TODO: see if I can shorten the board
    [led-usb-hub.kicad_pcb]
2024-01-13 Start Shortening, moved RP2040 as far -Y as possible, need to do the USB ports and LED lines
    [led-usb-hub.kicad_pcb]
2024-01-13 More shortening, need to move the USB Ports, will add zig-zags, also think about moving the USB Controller
    [led-usb-hub.kicad_pcb]
2024-01-14 More shortening, probably will do another pass of this, but the central usb port will be a challenge
    [led-usb-hub.kicad_pcb]
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2024-01-15 Prempt moving the USB IC by moving the USB Upstream Traces, can probably shift the whole board about 0.2 in total
    [led-usb-hub.kicad_pcb, led-usb-hub.kicad_sch]
2024-01-15 USB IC Moved, may be able to get it some more, but not gonna try right now TOOD: More the USB Ports Now
    [led-usb-hub.kicad_pcb]
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2024-01-16 Finish shrink TODO: Fancy Labels TODO: Test Points
    [led-usb-hub.kicad_pcb, led-usb-hub.kicad_sch]
2024-01-16 Fix some labels and mechanical sizes
    [led-usb-hub.kicad_pcb]
2024-01-16 Update models with better colors Export First Pass Step File for making a case
    [KSS221GLFS.stp, led-usb-hub.kicad_pcb]
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2024-01-18 Fix Values for LED Resistors, add Test Points
    [led-usb-hub.kicad_pcb, led-usb-hub.kicad_sch]
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2024-01-18 Update documentation with current designs and continue clean up
    [led-usb-hub.kicad_pcb]
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2024-01-18 Remove track through GND layer MAYBE TODO: swap crystals for a smaller package, condense the routing a bit
    [led-usb-hub.kicad_pcb]
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2024-01-19 Clean up schematic a little bit and switch to using correct power symbols
    [led-usb-hub.kicad_pcb, led-usb-hub.kicad_sch]
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2024-01-20 Use Net Classes Properly and lots of clean up
    [led-usb-hub.kicad_pcb, led-usb-hub.kicad_sch]
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2024-01-21 More clean up, better pin assignment for decoupling
    [led-usb-hub.kicad_pcb, led-usb-hub.kicad_sch]
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2024-01-22 Correct Annular Ring Sizes
    [led-usb-hub.kicad_pcb]
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2024-02-19 Switch 'Brightness' to 'Intensity', more technically correct
    [led-usb-hub.kicad_sch]
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2024-02-19 Update USB differential traces to match with the specifcations from JLC PCB (switch from PCBWay for pricing)
    [led-usb-hub-B_Cu (Sig).gbr, led-usb-hub-B_Mask.gbr, led-usb-hub-B_Paste.gbr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]
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2024-02-20 Fix Do Not Fit Resistor
    [led-usb-hub.kicad_pcb]
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2024-02-21 Fix hole size in PCB
    [led-usb-hub.kicad_pcb, led-usb-hub.kicad_sch]
2024-02-28 Update routing for 4mm screw hole Improve bom file (properly drop DNP, Test Points, and Holes
    [led-usb-hub.kicad_pcb]
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2024-03-03 Update Boot.Py to prevent keyboard prompting, in theory Also tracking in script to remount the device, because sometimes editing Boot.Py breaks
2024-03-05 Remove Power-On Monitor, was causing issues with device booting Switch to using a MAX809T for future revisions
    [led-usb-hub.kicad_pcb, led-usb-hub.kicad_sch]
2024-03-05 Fix POR Chip, I hope, to be tested when it arrives
    [led-usb-hub.kicad_pcb, led-usb-hub.kicad_sch]
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2025-05-21 [HW] Switch 3V3 Reg to AMS1117 Varaint (Maybe for a PCBWay Sponsorship)
    [led-usb-hub.kicad_sch]
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2025-06-07 [HW] Continue updating layout Route USB Traces Route LED Traces TODO: Finalize MCU, Oscillators, 3V3 Regs
    [led-usb-hub.kicad_pcb, led-usb-hub.kicad_sch]
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2025-06-07 [HW] Improve Routing and Diff Tune Params TODO: Finalize MCU choice (STM32 likely) TODO: Finalize 3V3 Regs (AMS1117 or something better) TODO: Pick new Oscillators TODO: SWD Conn Mod (NRST) (or 10 pi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
    [led-usb-hub.kicad_pcb]
2025-06-08 [HW] Pick MCU (STM32L552 48 pin LQFP) TODO: Oscillators TODO: 3V3 REGs TODO: Test Points (3 Voltages (VUSB, 3V3L, 3V3MCU), GND, TX/RX, PWR ON) TODO: Silks (Logos, Names, etc...) TODO: Screw Holes (do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
    [led-usb-hub.kicad_pcb, led-usb-hub.kicad_sch]
2025-06-08 [HW] Add Oscillaotrs and Test Points TODO: 3V3 Regs TODO: Silks (Logos, Names, etc...) TODO: Screw Holes (smaller than M3, those are huge) TODO: BOOT0 (and DFU HW Config)
    [KC2520Z8.00000C1KX00.step, led-usb-hub.kicad_pcb, led-usb-hub.kicad_sch]
2025-06-08 [HW] 3V3 Regs TODO: Re-annotate Board TODO: TVS Diode for USB TODO: Silks (Logos, Names, etc...) TODO: Screw Holes (smaller than M3, those are huge) TODO: BOOT0 (and DFU HW Config)
    [IHLP2020CZ.step, TLV62569PDDCR.step, led-usb-hub.kicad_pcb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]
2025-06-08 [HW] Add Silks and USB TVS Diode TODO: Re-annotate TODO: BOOT0 Switch to enable DFU TODO: Add SWD Connector (include NRST) TODO: Mounting Options
    [led-usb-hub.kicad_pcb, led-usb-hub.kicad_sch]
2025-06-08 [HW] Added Boot SW (for DFU Mode, and swapped to smaller switches), Added SWD Connector, Swapped to smaller Inductors TODO: Re-annotate by group TODO: Mounting
    [EVQ-P7L01P.step, IND_SRP4020FA-2R2M_BRN.step, led-usb-hub.kicad_pcb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]
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2025-06-09 [HW] Added MAX809 PWR Supervisor IC and jumper in case PG from Reg isn't good enough
    [led-usb-hub.kicad_pcb, led-usb-hub.kicad_sch]
2025-06-10 [HW] Fix ESD Diode placement
    [led-usb-hub.kicad_pcb, led-usb-hub.kicad_sch]
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2025-06-13 [HW] Remove Mounting Holes TODO: Move USB Ports/Board Edges Around to get connectors with correct stickout (1.2mm?)
    [led-usb-hub.kicad_pcb, led-usb-hub.kicad_sch]
2025-06-13 [HW] Rearrange to allow port hangover board edge (better for case) TODO: Figure out mounting/alignment Case might provide all mounting and just need registration So could add semi-circles on board ed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
    [led-usb-hub.kicad_pcb]
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2025-06-18 [SW] Setup PWM Timers (maybe correctly, need to check with logic analyzer (for freq and polarity)
    [LED_USB_HUB.ioc]
2025-06-25 [SW] First Pass at code Not Working, need debugger
    [LED_USB_HUB.ioc]
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

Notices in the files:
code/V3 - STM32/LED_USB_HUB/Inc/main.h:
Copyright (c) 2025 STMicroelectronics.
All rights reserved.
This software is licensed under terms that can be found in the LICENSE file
